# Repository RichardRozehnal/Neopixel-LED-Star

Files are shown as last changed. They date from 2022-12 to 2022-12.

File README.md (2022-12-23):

# Neopixel LED Star

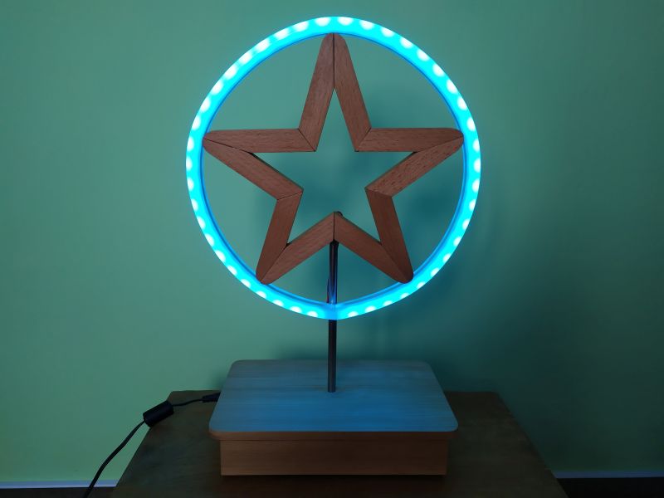
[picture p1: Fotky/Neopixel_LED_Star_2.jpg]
Neopixel LED Star


Hvězda se 44 neopixel LEDkami zobrazuje 21 efektů. Efekty se automaticky přepínají po 2 minutách, ale je možné je přepínat i ručně tlačítkem. Tlačitkem lze také volit barvu LEDek a jejich jas.

#### Funkce tlačítka:
1 stisk přepíná efekty (celkem 21 efektů + jedna pozice pro automatické přepínání)  
2 rychlé stisky mění barvu (pouze při efektu, který používá jednu barvu)  
1 dlouhý stisk mění jas LEDek (celkem 5 nastavení jasu)  

## Seznam součástek

| Ref | Qnty | Value | Cmp name |
|:---:|:----:|:---:|:---:|
| C1, | 1 | 1000uF/10V | C_Polarized |
| C2, C3,  | 2 | 10uF | C |
| C4, C6,  | 2 | 100nF | C |
| C5, | 1 | 4u7 | C |
| J1, | 1 | Power Supply Jack | Conn_01x02 |
| J2, | 1 | Neopixel solder points | Conn_01x03 |
| J3, | 1 | Programming Connector  | Conn_01x04 |
| R1, | 1 | 470R | R |
| SW1, | 1 | Switch | SW_Push |
| U1, | 1 | HT7533 | HT75xx-1-SOT89 |
| U2, | 1 | STM32G031J6M6 | STM32G031J6M6 |
| U3, | 1 | 74AHCT1G125QW5-7 | 74AHCT1G125QW5-7 |

## Další fotky

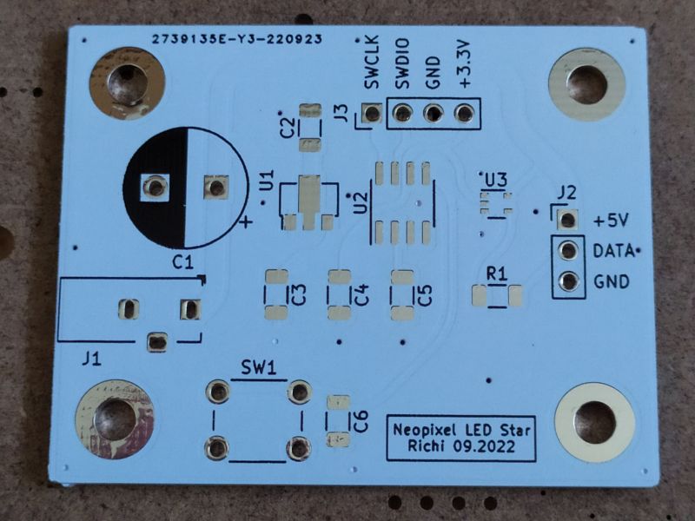
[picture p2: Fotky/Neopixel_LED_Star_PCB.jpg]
Neopixel LED Star PCB

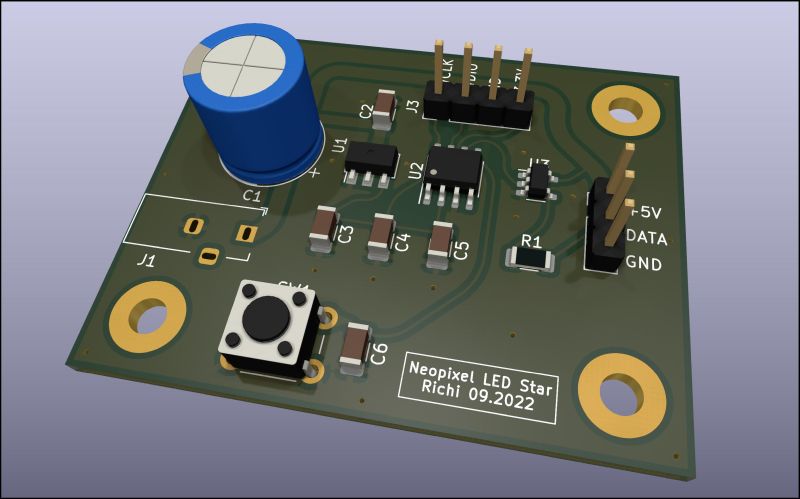
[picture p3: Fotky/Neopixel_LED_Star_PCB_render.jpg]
Neopixel LED Star PCB render

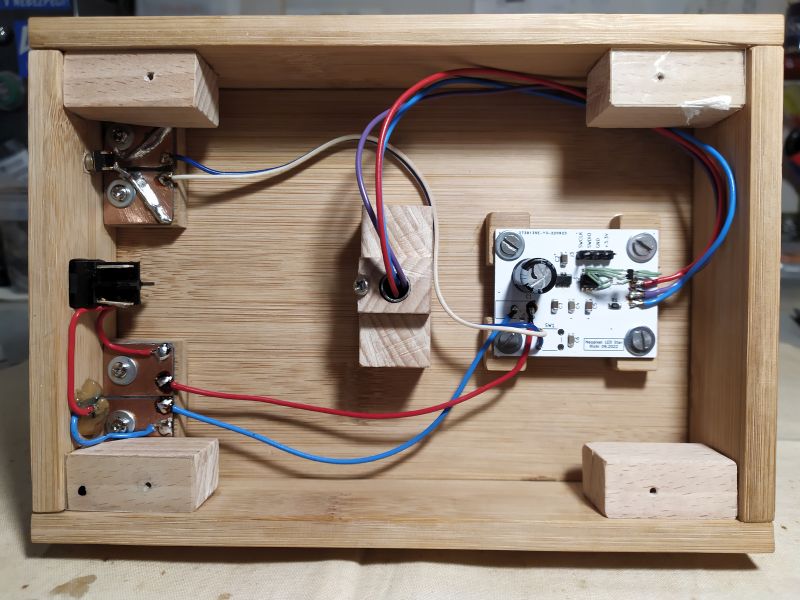
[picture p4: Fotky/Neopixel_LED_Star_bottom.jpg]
Neopixel LED Star bottom

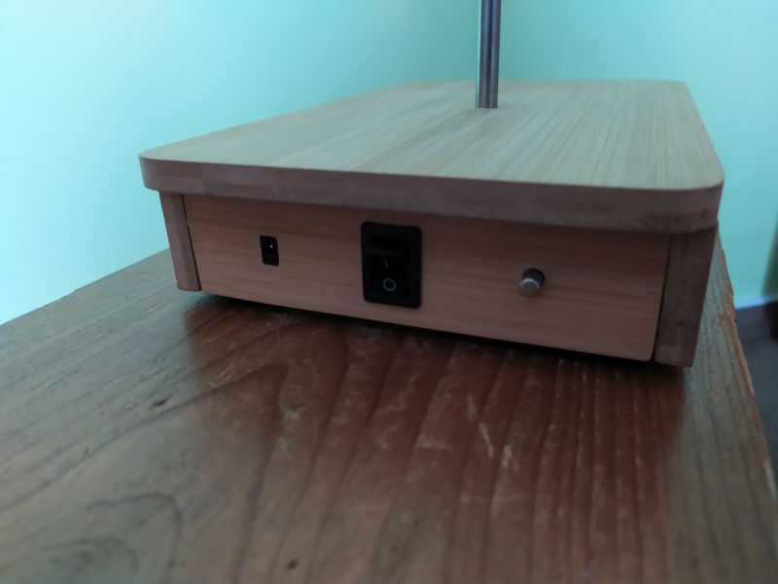
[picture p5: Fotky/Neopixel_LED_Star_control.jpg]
Neopixel LED Star control


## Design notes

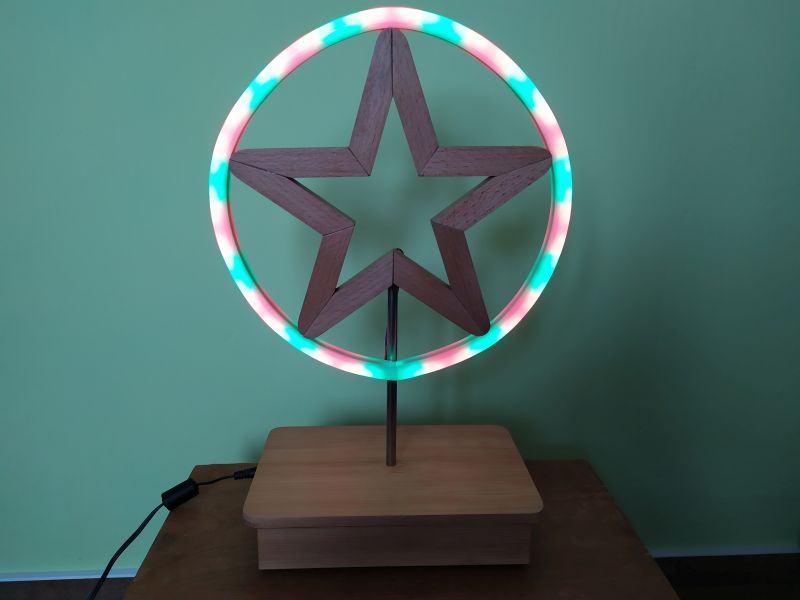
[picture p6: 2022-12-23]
Fotky/Neopixel_LED_Star_6.jpg

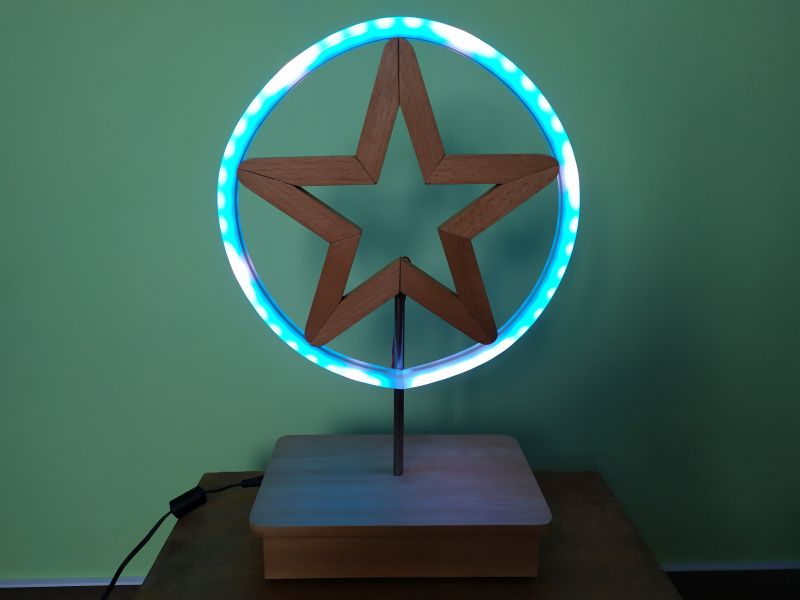
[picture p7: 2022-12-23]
Fotky/Neopixel_LED_Star_5.jpg

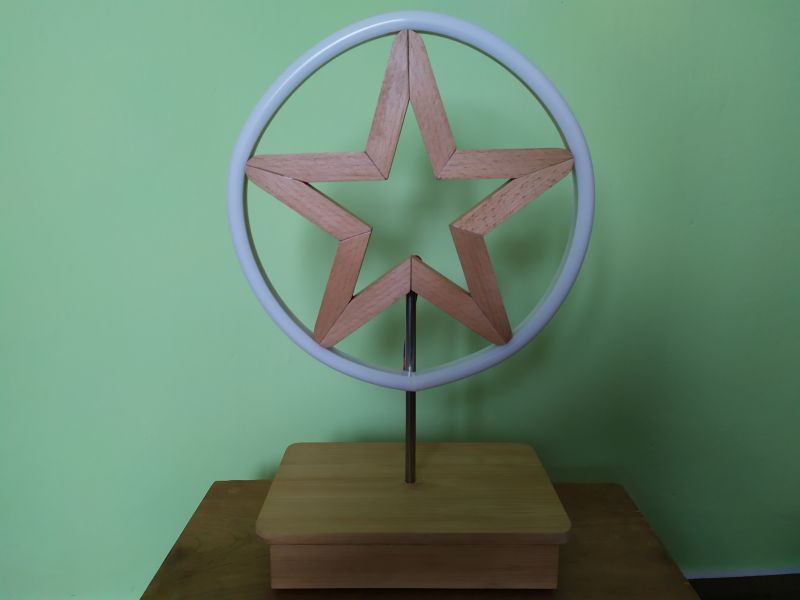
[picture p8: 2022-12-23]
Fotky/Neopixel_LED_Star_1.jpg

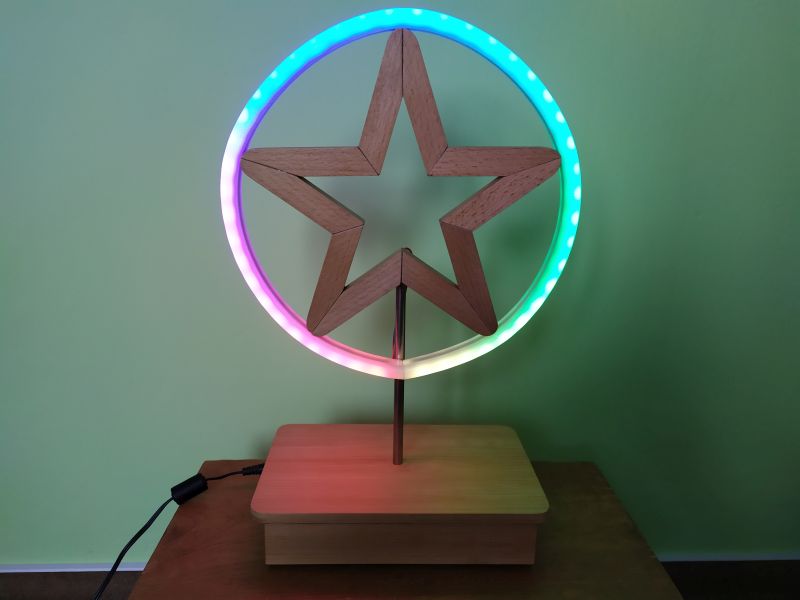
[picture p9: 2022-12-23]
Fotky/Neopixel_LED_Star_8.jpg

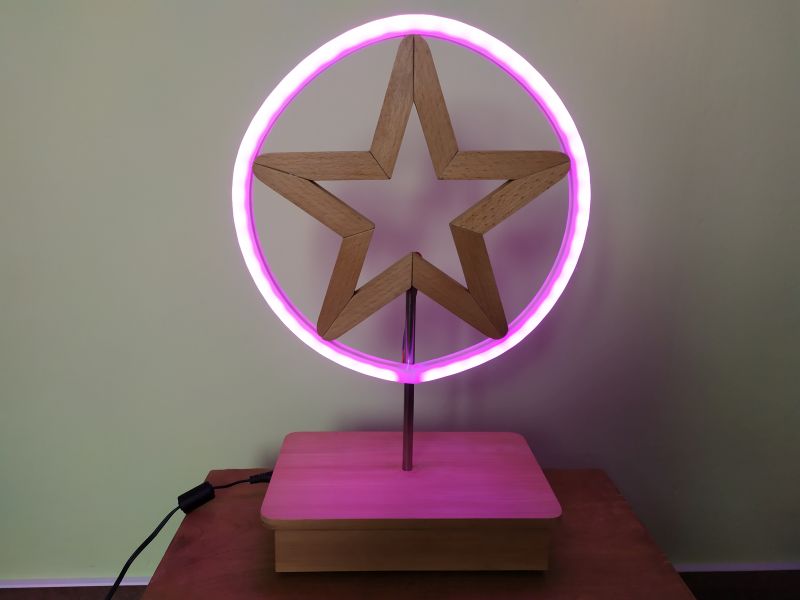
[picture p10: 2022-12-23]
Fotky/Neopixel_LED_Star_7.jpg

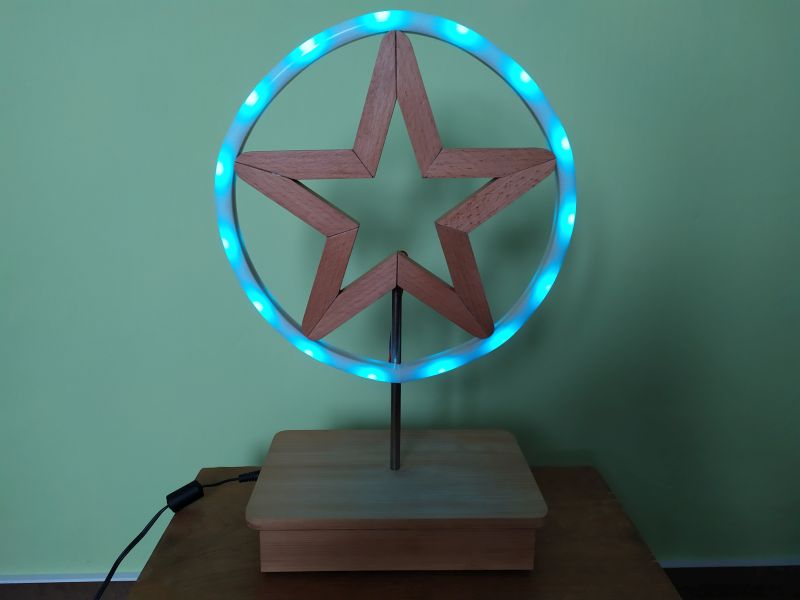
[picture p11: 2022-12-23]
Fotky/Neopixel_LED_Star_4.jpg

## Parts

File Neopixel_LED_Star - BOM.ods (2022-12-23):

Neopixel LED Star – BOM
Ref | Qnty | Value | Cmp name | Footprint | Description
C1, | 1 | 1000uF/10V | C_Polarized | Neopixel_LED_Star:CP_Radial_D10.0mm_P5.00mm | Polarized capacitor
C2, C3, | 2 | 10uF | C | Neopixel_LED_Star:C_1206_3216Metric | Unpolarized capacitor
C4, C6, | 2 | 100nF | C | Neopixel_LED_Star:C_1206_3216Metric | Unpolarized capacitor
C5, | 1 | 4u7 | C | Neopixel_LED_Star:C_1206_3216Metric | Unpolarized capacitor
J1, | 1 | Power Supply Jack | Conn_01x02 | Neopixel_LED_Star:BarrelJack_Horizontal_3.5x1.3 | Generic connector, single row, 01x02, script generated (kicad-library-utils/schlib/autogen/connector/)
J2, | 1 | Neopixel solder points | Conn_01x03 | Neopixel_LED_Star:PinHeader_1x03_P2.54mm_Vertical | Generic connector, single row, 01x03, script generated (kicad-library-utils/schlib/autogen/connector/)
J3, | 1 | Programming Connector | Conn_01x04 | Neopixel_LED_Star:PinHeader_1x04_P2.54mm_Vertical | Generic connector, single row, 01x04, script generated (kicad-library-utils/schlib/autogen/connector/)
R1, | 1 | 470R | R | Neopixel_LED_Star:R_1206_3216Metric | Resistor
SW1, | 1 | Switch | SW_Push | Neopixel_LED_Star:SW_PUSH_6mm_H4.3mm | Push button switch, generic, two pins
U1, | 1 | HT7533 | HT75xx-1-SOT89 | Neopixel_LED_Star:SOT-89-3 | 100mA Low Dropout Voltage Regulator, Fixed Output, SOT89
U2, | 1 | STM32G031J6M6 | STM32G031J6M6 | Neopixel_LED_Star:SOIC-8_3.9x4.9mm_P1.27mm | ArmÂ® 32-bit CortexÂ®-M0+ CPU, frequency up to 64 MHz, 32kB Flash Memory, 8kB SRAM
U3, | 1 | 74AHCT1G125QW5-7 | 74AHCT1G125QW5-7 | Neopixel_LED_Star:SOT-23-5 | Single Buffer Gate Tri-State, Low-Voltage CMOS

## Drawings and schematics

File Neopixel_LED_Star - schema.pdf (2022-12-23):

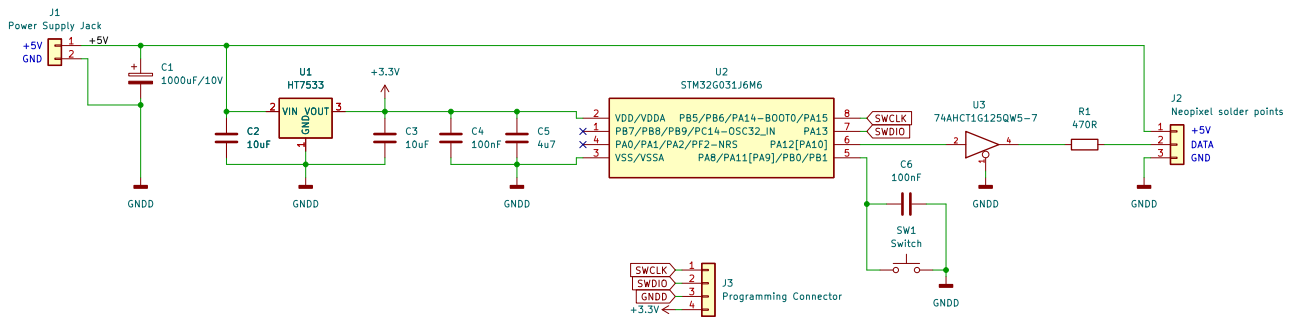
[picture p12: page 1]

Id: 1/1 Title: Neopixel LED Star

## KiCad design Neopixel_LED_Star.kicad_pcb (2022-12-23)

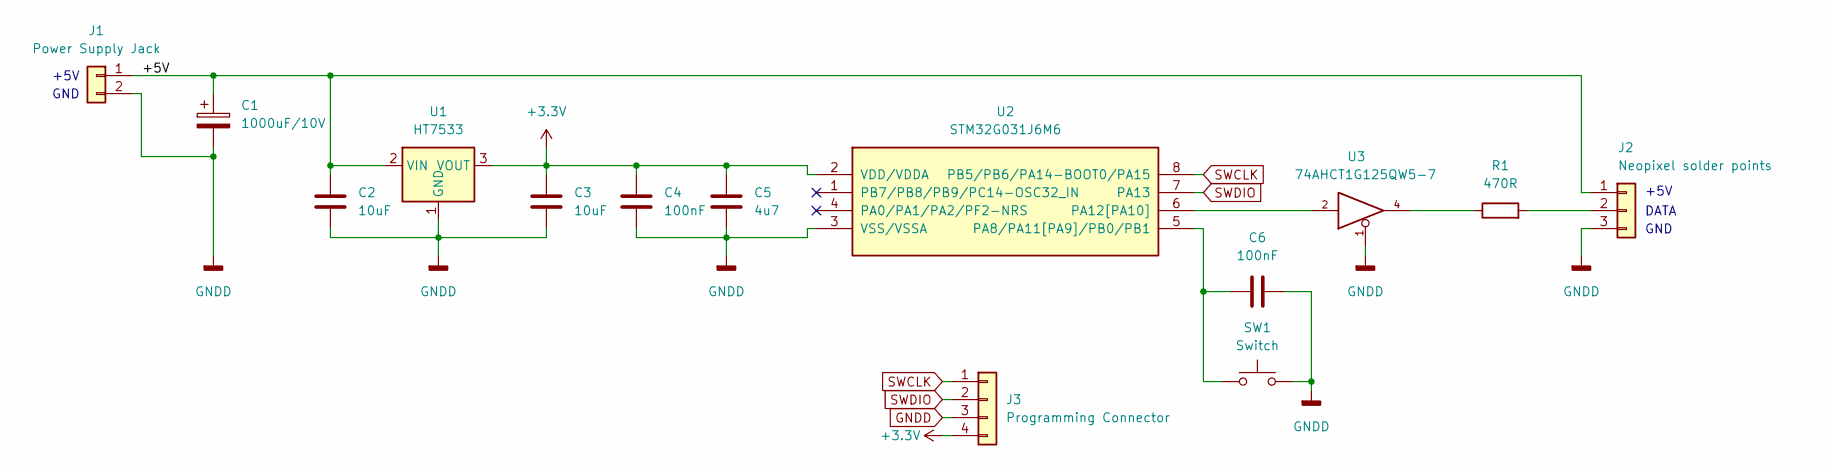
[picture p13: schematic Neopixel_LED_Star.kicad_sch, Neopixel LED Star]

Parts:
C1: 1000uF/10V; CP_Radial_D10.0mm_P5.00mm
C2, C3: 10uF; C_1206_3216Metric
C4, C6: 100nF; C_1206_3216Metric
C5: 4u7; C_1206_3216Metric
J1: Power Supply Jack; BarrelJack_Horizontal_3.5x1.3
J2: Neopixel solder points; PinHeader_1x03_P2.54mm_Vertical
J3: Programming Connector; PinHeader_1x04_P2.54mm_Vertical
R1: 470R; R_1206_3216Metric
SW1: Switch; SW_PUSH_6mm_H4.3mm
U1: HT7533; SOT-89-3
U2: STM32G031J6M6; SOIC-8_3.9x4.9mm_P1.27mm
U3: 74AHCT1G125QW5-7; SOT-23-5

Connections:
+3V3: C3.1, C4.1, C5.1, J3.4, U1.3 (VOUT), U2.2 (VDD/VDDA)
+5V: C1.1, C2.1, J1.1, J2.1, U1.2 (VIN), U3.5 (+5V)
GNDD: C1.2, C2.2, C3.2, C4.2, C5.2, C6.2, J1.2, J2.3, J3.3, SW1.2, U1.1 (GND), U2.3 (VSS/VSSA), U3.1, U3.3 (GNDD)
unnamed: C6.1, SW1.1, U2.5 (PA8/PA11[PA9]/PB0/PB1)
unnamed: J2.2, R1.2
unnamed: R1.1, U3.4
unnamed: U2.6 (PA12[PA10]), U3.2
SWCLK: J3.1, U2.8 (PB5/PB6/PA14-BOOT0/PA15)
SWDIO: J3.2, U2.7 (PA13)

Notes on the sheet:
+5V
DATA
GND

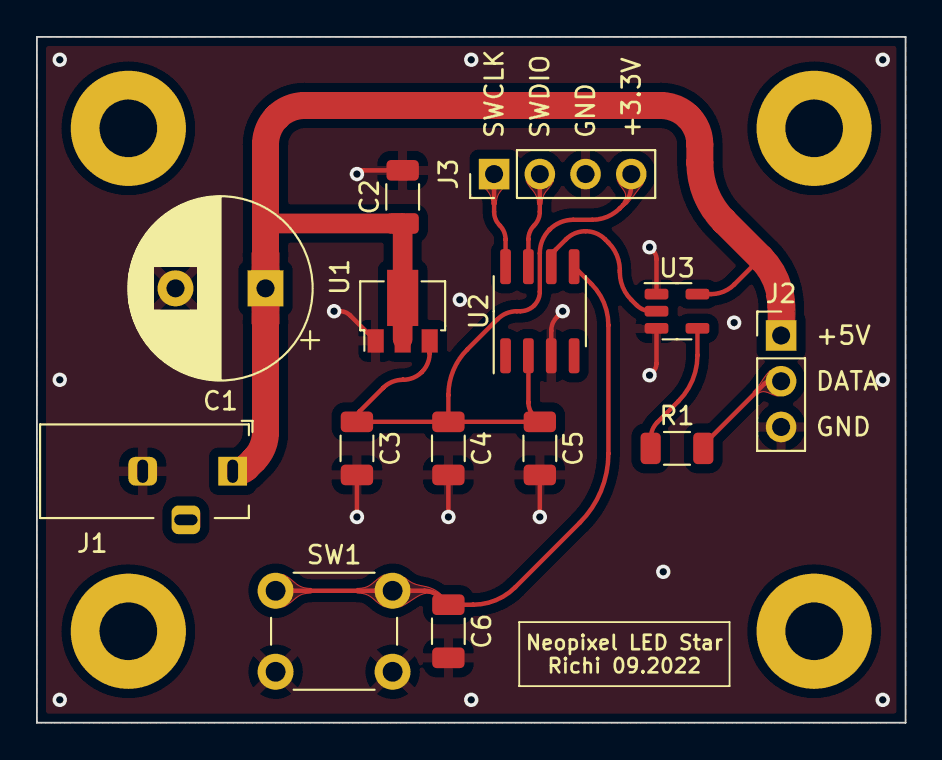
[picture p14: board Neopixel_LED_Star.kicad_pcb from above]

Board: 2 copper layers, 48.3 x 38.1 mm, 14 parts (0 on the bottom side), 9 nets.
